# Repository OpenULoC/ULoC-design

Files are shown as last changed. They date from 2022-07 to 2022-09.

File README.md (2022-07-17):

# ULoC: design
Brainstorming and high-level [design](design.md) towards the ULoC.

## The ULoC
The **Universal Lab-on-a-Chip** (**ULoC**) is a hypotetical device capable of carrying out
a wide variety of laboratory tasks in an automatic, programmable manner.

In this regard, it seeks to provide the same advantages that a regular
[LoC](https://en.wikipedia.org/wiki/Lab-on-a-chip) offers, namely high throughput and low cost.
Additionally, the **OpenULoC** project is intended to create an Open Source incarnation
of this machine, opening up the doors to affordable research.

## Goals
Scientific research is neither cheap nor fast;
much of the funds are spent in expensive products and specialized equipment.
Cutting times or increasing quality is difficult,
as it often entails obtaining even less affordable equipment.

Same goes for medical practice.
There is an increasing market for biological and genetic therapies,
both of which are prohibitively expensive at the moment.
Reducing the barrier of entry to the manufacture of these products
could prove key to reducing health costs,
especially in developing countries.

## Scope
The ULoC will be initially limited to Molecular Biology experiments, tests and processes.
This is due to the fact that this field is effectively "low-hanging fruit" for
the goals exposed above, with many Cell Biology procedures depending on biomolecule products
and Organic Chemistry being very non-trivial to implement as solid-state circuitry.

This could include any of the following.

* Standard enzyme-catalyzed reactions.
* Nucleic acid amplification.
* Some antibody-mediated tests.
* Basic substance identification.
* _In vitro_ gene expression.
* _In vitro_ gene editing.
* Polynucleotide synthesis.

## Tools

> The trajectory of 3D printing will most certainly raise real grievances,
> from solid state meth labs, to ceramic knives.
> 
> - Cory Doctorow

This is a non-comprehensive list of tools that have been, or could be, helpful to this project.
They have been chosen over alternatives so as to avoid vendor lock or increasing costs.

* Standard FFF 3D printers
* [Cura by Ultimaker](https://github.com/Ultimaker/Cura)
* [OpenSCAD](https://github.com/openscad/openscad)
* [KiCAD](https://gitlab.com/kicad)
* [fluidics by aerkiaga](https://github.com/aerkiaga/fluidics)
* [OpenFOAM](https://github.com/OpenFOAM)
* [Rust](https://www.rust-lang.org/)

## Design
See [design.md](design.md).

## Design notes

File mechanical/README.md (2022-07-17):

# Mechanical design
The mechanical floor will output controlled rotary motion to the hydraulic floor above.
This motion will be carried via multiple transmission lines.

## Motors
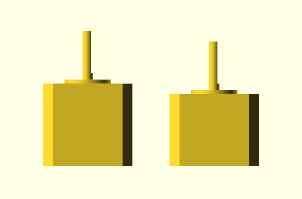
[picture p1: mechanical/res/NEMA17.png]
Two NEMA17 motors


Widely available **NEMA17** stepper motors will be used.
These are commonly used for consumer products such as
[3D printers](https://reprap.com/wiki/NEMA_Motor).

There's a table of widely available such motors
[here](https://reprap.org/wiki/NEMA_17_Stepper_motor#Common_Stepper_Motor_Models);
ideally, a wide variety of models from that table should be usable,
to allow scrap parts to be used (e.g. a typical 3D printer has exactly 4 steppers).

## Multiplexers
Due to the relatively high cost of stepper motors and the slow pace of typical experiments,
it only makes sense to use a small number of steppers and
couple them to many transmission lines by means of mechanical multiplexers.

A reasonable default would be two independent motors, each controlling a number of axes.
Since each multiplexer requires a further stepper to select the output axis,
that amounts to four motors in total, the exact number present in typical consumer 3D printers.

Ideally, the multiplexer itself should only consist of inexpensive, widely available
hardware store parts and 3D printed elements.

See [mux](mux.md) for designs.

## Transmission lines
There are many ways to transmit a rotating motion:

* Belts: low durability and accuracy; flexible but now always simple to implement.
* CV joints: good characteristics, but expensive.
* Bevel gears: complex but accurate, and cheap if 3D printed.

A nice solution is to use threaded rods and bevel gears at right angles.

See [elbow](elbow.md) for designs.

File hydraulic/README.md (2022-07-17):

# Hydraulic design
The hydraulic floor will receive mechanical input from the mechanical floor below.
It will contain syringe pumps and valves, and will connect via tubes to the floors above.
Any input and output containers will be situated outside the stack.

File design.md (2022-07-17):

# High-level design

## Design principles

* Open standards, open source
* Modularity and extensibility
* Low cost
* Reliability

## Block diagram

ULoC block diagram

The ULoC itself will consist of many layers or floors,
physically stacked over one another.
The first of these will contain an MCU and enough electronics to
control the machine and interface with a client machine.

The second floor will host [mechanical](mechanical/README.md) actuators and transmission mechanisms.
These should have a focus on affordability.

The third floor will contain syringe pumps, valves and other "clean"
[hydraulic](hydraulic/README.md) components.
These will receive input from all mechanical transmission lines arriving from below.
General inputs and outputs will be located outside the stack.

Finally, any subsequent floors will have room for the actual effectors and sensors,
including any fluidic channels and any electronics necessary for their operation.

All of this will be controlled by an Open Source firmware on the MCU and
a specialized software suite on the client machine (when connected).
This is quite a sweet spot for making sure the system is reliable.

Specialized laboratory protocols will be necessary,
those shall be encoded and provided for performing automated tasks and maintenance.

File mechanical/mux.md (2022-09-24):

# Mechanical multiplexer design

## Design 1
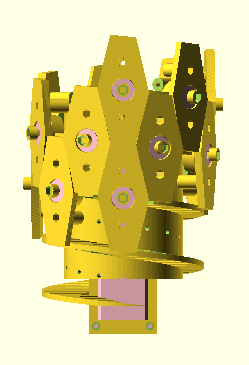
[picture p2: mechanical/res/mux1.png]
Design 1 in OpenSCAD


[Files](mux1)

A spiral staircase design.
Both motors are mounted inside the structure,
which rotates and moves to choose an axis.
It allows the number of axes to be easily and modularly increased.

Drawbacks:
* Only supports two specific motor models.
* The heavy motors are mounted inside the structure.
* Unnecessary friction between some moving parts.
* High vertical clearance needed.
* Complex design.

## Design 2
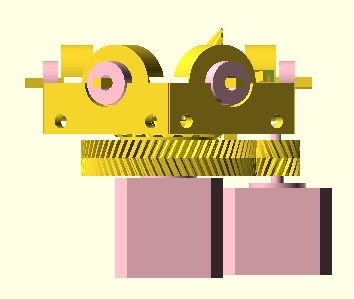
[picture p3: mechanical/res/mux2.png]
Design 2 in OpenSCAD


[Files](mux2)

A much simpler design.
Motors are fixed, and mounted underside the mechanism.
NEMA17 motors of any length can be used.
Makes use of adhesive to fix bearings in place.

Drawbacks:
* Structure may be unstable.
* Requires extra pieces for support, which depend on motor length.
* Fixed number of output axes: 6.
* To select a new axis, the input shaft must also be rotated in tandem.

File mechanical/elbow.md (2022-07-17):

# Geared elbow design

## Design 1
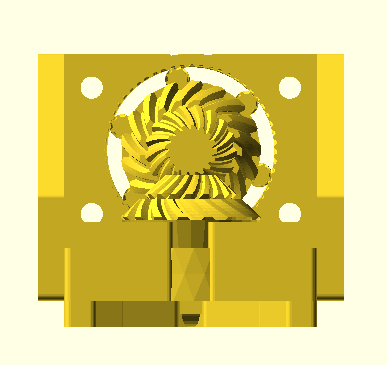
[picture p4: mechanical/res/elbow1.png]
Design 1 in OpenSCAD


[Files](elbow1)

A sturdy elbow with 3D printed gear bearings.
It's designed to connect two M5 threaded rods,
plus using a few M3 nuts and bolts in its build.
All remaining components can be 3D printed.

The design has been built, and unfortunately
the printed gear bearings quickly fail.

## Design 2
Work in progress, will use cheap ball bearings.

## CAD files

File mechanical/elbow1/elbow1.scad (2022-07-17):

use <../lib/octoid_gear_types.scad>
use <../lib/mesh_bevel_gear.scad>
use <../lib/gear_bearing.scad>

// 0 or undef for full assembly
// 1 - 5 for individual pieces
do_piece = undef;

// set true for final render
// set false for faster viewing
high_detail = true;


$fs = high_detail ? 0.3 : $fs;
$fn = high_detail ? 30 : $fn;

module half_elbow_mechanism(
    reverse = false, rotation = 0
) {
    angle = fn_bevel_angle_for_gear_ratio(1);
    height = sin(angle) * 15;
    radius = cos(angle) * 15;

    coef = 1.4;
    difference() {
        union() {
            intersection() {
                mirror([0, 0, 1]) cylinder(22, 20, 0);
                rotate(rotation, [0, 0, 1])
                octoid_helical_gear(
                    15, 0.7, false,
                    reverse ? -1 : 1,
                    angle, 17, addendum_coefficient = 0.6
                );
            }
            
            translate([0, 0, -9])
            rotate(rotation, [0, 0, 1])
            cylinder(2, 7, 6);
            
            intersection() {
                mirror([0, 0, 1]) cylinder(16, 12, 0);
                rotate(rotation, [0, 0, 1])
                octoid_helical_gear(
                    10.5, 0.5, false,
                    reverse ? 1 : -1,
                    angle, 17, addendum_coefficient = 0.6
                );
            }

            translate([0, 0, -coef*height])
                cylinder((coef-1)*height, 0.6*coef*radius, radius);
        
        
            translate([0, 0, -coef*height - 8])
                gear_bearing(
                    8, coef*radius, 0.6, false,
                    40, 6,
                    planet_tooth_count = 8,
                    rotation_angle = rotation,
                    tolerance = 0.2
                );
        }
        
        translate([0, 0, -coef*height - 8 - 0.1])
            cylinder(10 + 0.1, 2.75, 2.75); // M5 clearance hole, normal fit
                
        translate([0, 0, -coef*height + 2 - 0.1])
            cylinder(6, 2.75, 0);  
                
        translate([0, 0, -coef*height - 8 - 0.1])
        linear_extrude(4.7) // M5 hexagon nut height
        scale([4.4, 4.4]) // M5 hexagon nut radius
        polygon([
            for(phi = [0:60:360])
                [cos(phi), sin(phi)]
        ]);
                
        translate([0, 0, -coef*height - 3.3 - 0.1])
        linear_extrude(7, scale = 0)
        scale([4.4, 4.4])
        polygon([
            for(phi = [0:60:360])
                [cos(phi), sin(phi)]
        ]);
    }
}

module half_elbow_corners() {
    angle = fn_bevel_angle_for_gear_ratio(1);
    height = sin(angle) * 15;
    radius = cos(angle) * 15;
    
    coef = 1.4;
    inner_coord = 0.9*coef*radius/sqrt(2);
    
    translate([0, 0, -coef*height - 8])
    linear_extrude(8)
    for(phi = [0:90:360]) {
        rotate(2*phi, [0, 0, 1])
        scale([1, phi >= 180 ? -1 : 1, 1])
        difference() {
            offset(1)
            offset(-1)
            polygon([
                [coef*radius, 0],
                [coef*radius, 1.3*coef*radius],
                [-1, 1.3*coef*radius],
                [-1, 0.99*coef*radius],
                [1.11*inner_coord, 1.11*inner_coord],
                [0.9*coef*radius, 2]
            ]);
            translate([1.02*inner_coord, 1.6*inner_coord])
            circle(d=3.4); // M3 clearance hole, normal fit
        }
    }
}

module elbow_connector() {
    angle = fn_bevel_angle_for_gear_ratio(1);
    height = sin(angle) * 15;
    radius = cos(angle) * 15;
    
    coef = 1.4;
    inner_coord = 0.9*coef*radius/sqrt(2);
    clearance = 0.0;
    
    for(phi = [0:90:360]) {
        rotate(phi % 180 > 0 ? -90 : 0, [0, 1, 0])
        scale([phi % 180 > 0 ? -1 : 1, 1, 1])
        translate([0, 0, -coef*height - 12 - clearance])
        linear_extrude(4)
        scale([1, phi >= 180 ? -1 : 1, 1])
        difference() {
            offset(1)
            offset(-1)
            polygon([
                [1.5*coef*radius, 0],
                [1.5*coef*radius, 1.3*coef*radius],
                [-1, 1.3*coef*radius],
                [-1, 0.99*coef*radius],
                [1.11*inner_coord, 1.11*inner_coord],
                [0.9*coef*radius, 2]
            ]);
            translate([1.02*inner_coord, 1.6*inner_coord])
            circle(d=3.4); // M3 clearance hole, normal fit
        }
    }
    
    translate([
        coef*height + clearance,
        1.3*coef*radius,
        -coef*height - clearance
    ])
    mirror([0, 0, 1])
    rotate(90, [1, 0, 0])
    linear_extrude(2.6*coef*radius)
    {
        square(10);
        
        offset(5)
        offset(-5)
        square(12);
    }
}

module elbow_support() {
    angle = fn_bevel_angle_for_gear_ratio(1);
    height = sin(angle) * 15;
    radius = cos(angle) * 15;
    
    coef = 1.4;
    inner_coord = 0.9*coef*radius/sqrt(2);
    clearance = 0.0;
    
    for(phi = [0:90:180]) {
        rotate(phi % 180 > 0 ? -90 : 0, [0, 1, 0])
        scale([phi % 180 > 0 ? -1 : 1, 1, 1])
        translate([0, 0, -coef*height + clearance])
        linear_extrude(4)
        scale([-1, 1, 1])
        difference() {
            offset(1)
            offset(-1)
            polygon([
                [coef*radius, 0],
                [coef*radius, 1.5*coef*radius],
                [-1, 1.5*coef*radius],
                [-1, 0.99*coef*radius],
                [1.11*inner_coord, 1.11*inner_coord],
                [0.9*coef*radius, 2]
            ]);
            translate([1.02*inner_coord, 1.6*inner_coord])
            circle(d=3.4); // M3 clearance hole, normal fit
        }
    }
    
    translate([
        coef*radius - clearance,
        1.3*coef*radius + clearance,
        -coef*radius + clearance
    ])
    rotate(-90, [1, 0, 0])
    rotate(180, [0, 0, 1])
    linear_extrude(4 - clearance)
    offset(1)
    offset(-1)
    polygon([
        [-8, -8],
        [2*coef*radius - clearance, -8],
        [2*coef*radius - clearance, 8 - clearance],
        [8 - clearance, 2*coef*radius - clearance],
        [-8, 2*coef*radius - clearance]
    ]);
}

/// FULL ANIMATED ASSEMBLY ///
rotate(360 * $t, [0, 0, 1])
if(!do_piece) {
    half_elbow_mechanism(false, 360 * $t);
    half_elbow_corners();
    mesh_bevel_gear(0, 1, 17)
        half_elbow_mechanism(true, -360 * $t);
    rotate(90, [0, -1, 0])
        half_elbow_corners();
    elbow_connector();
    elbow_support();
    mirror([0, 1, 0])
        elbow_support();
}

/// PIECE 1 ///
if(do_piece == 1) {
    half_elbow_mechanism(false);
    half_elbow_corners();
}

/// PIECE 2 ///
if(do_piece == 2) {
    half_elbow_mechanism(true);
    half_elbow_corners();
}

/// PIECE 3 ///
if(do_piece == 3) {
    elbow_connector();
}

/// PIECE 4 ///
if(do_piece == 4) {
    rotate(-90, [1, 0, 0])
        elbow_support();
}

/// PIECE 5 ///
if(do_piece == 5) {
    rotate(90, [1, 0, 0])
    mirror([0, 1, 0])
        elbow_support();
}

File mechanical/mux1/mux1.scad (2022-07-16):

use <../lib/cycloid_gear_types.scad>
use <../lib/mesh_parallel_gear.scad>

// 0 or undef for full assembly
// 1 - 12 for individual pieces
do_piece = undef;

/*
Piece   Count   Description
1       1       Motor housing half 1
2       1       Motor housing half 2
3       1       Output segment
4       1       Sun gear
5       2       Planet gear
6       1       Helix, bottom
7       1       Helix, top
8       1       Fixed gear
9       15      Output shaft
10      15      Output adapter
11      15      Output housing
12      1       Base
*/

// set true for final render
// set false for faster viewing
high_detail = true;


$fs = high_detail ? 0.1 : $fs;
$fn = high_detail ? 100 : $fn;

module NEMA17_motor(length) {
    linear_extrude(length)
    polygon([
        /*[21.15, 15.5],
        [15.5, 21.15],
        [-15.5, 21.15],
        [-21.15, 15.5],
        [-21.15, -15.5],
        [-15.5, -21.15],
        [15.5, -21.15],
        [21.15, -15.5],*/
        [21.15, 16.5],
        [16.5, 21.15],
        [-16.5, 21.15],
        [-21.15, 16.5],
        [-21.15, -16.5],
        [-16.5, -21.15],
        [16.5, -21.15],
        [21.15, -16.5],
    ]);
    translate([0, 0, length])
    cylinder(2, d=22, false);
    translate([0, 0, length])
    difference() {
        cylinder(25, d=5, false);
        translate([4, 0, 15])
        cube([5, 5, 20], true);
    }
}

module bearing_606_2RS() {
    difference() {
        cylinder(6, d=17, false);
        translate([0, 0, -0.5])
        cylinder(7, d=6, false);
    }
}

module M3_bolt() {
    cylinder(20, d=3.4);
    mirror([0, 0, 1])
    cylinder(2, d=6);
}

module M3_hexagon_profile() {
    //radius = 3.2;
    radius = 3.5;
    polygon([ for(phi = [0:60:360]) [
        radius * cos(phi), radius * sin(phi)
    ]]);
}

module stacked_motors() {
    //small motor
    translate([-17, 0, 0])
    rotate(90, [0, 1, 0])
    NEMA17_motor(34);
    //large motor
    rotate(180, [0, 0, 1])
    translate([0, 0, -25 - 39 - 21.3 - 5])
    NEMA17_motor(39);
}

module m3_hole(y, z) {
    translate([0, y, z])
    rotate(90, [0, 1, 0]) {
        translate([0, 0, -20])
            cylinder(50, d=3.4, false);
        translate([0, 0, -20])
            cylinder(12, d=6, false);
        translate([0, 0, 20])
        mirror([0, 0, 1])
        linear_extrude(13)
            M3_hexagon_profile();
    }
}

module motor_housing() {
    difference() {
        translate([0, 0, -35.5])
            cube([38, 50, 130], true);
        stacked_motors();
        translate([-10, 0, 25])
            cube([20, 20, 12], true);
        translate([0, 0, -35])
            cube([30, 60, 24], true);
        m3_hole(20, 22);
        m3_hole(-20, 22);
        m3_hole(20, -95);
        m3_hole(-20, -95);
    }
}

module helix(
    turns = 4,
    inner_radius = 27,
    outer_radius = 60,
    turn_height = 40,
    height_proportion = 0.1
) {
    height = turn_height * turns;
    twist = 360 * turns;
    angle = height_proportion * 180;
    
    intersection() {
        linear_extrude(height, twist = twist, slices = turns * 3 * $fn, convexity = turns + 1)
        rotate(-angle, [0, 0, 1])
        projection()
        rotate_extrude(angle = 2 * angle, convexity = 1)
        polygon([
            [1.2*outer_radius, 1],
            [1.2*outer_radius, -1],
            [inner_radius, -1],
            [inner_radius, 1]
        ]);
        cylinder(height, r=outer_radius);
    }
}

module output_sector() {
    difference() {
        rotate(180, [1, 0, 0])
        intersection() {
            union() {
                translate([0, 0, -40])
                    helix(4, 45);
                rotate(90, [0, 1, 0])
                    cylinder(49, 3.5, 3.5);
            }
            rotate(90, [0, 1, 0])
                cylinder(60, 0, 20);
        }
        translate([0, 0, -10])
            cylinder(20, r=25, true);
        stacked_motors();
    }
}

sun_teeth = 16;
sun_radius = 5;
fixed_radius = 35;

fixed_teeth = sun_teeth * fixed_radius / sun_radius;
planet_radius = (fixed_radius - sun_radius) / 2;
planet_teeth = sun_teeth * planet_radius / sun_radius;

module fixed_helix() {
    difference() {
        translate([0, 0, -80])
            helix(4, 0);
        rotate(90, [0, 1, 0])
            cylinder(110, 0, 45);
        translate([0, 0, -32.5])
            cube([38, 50, 127], true);
        stacked_motors();
        translate([0, -sun_radius - planet_radius, -40])
            cylinder(20, 1.1*planet_radius, 1.1*    planet_radius);
        translate([0, sun_radius + planet_radius, -60])
            cylinder(20, 1.1*planet_radius, 1.1*    planet_radius);
    }
}

module fixed_gear() {
    difference() {
        translate([0, 0, -60])
        cycloid_spur_gear(130, fixed_radius, false,
            fixed_teeth, true, 44);
        translate([0, 0, -80])
        helix(4, 0, 60, 40, 0.2);
        for(phi = [-360:360/15:864]) {
            translate([0, 0, 40 * phi / 360])
            rotate(-phi, [0, 0, 1]) {
                translate([fixed_radius + 3, 0, 0])
                rotate(90, [0, 1, 0])
                translate([20, 0, 0]) {
                    M3_bolt();
                    translate([0, 0, -10])
                    cylinder(10, d=6);
                }
            }
        }
    }
}

module sun_gear() {
    difference() {
        translate([0, 0, -45])
        cycloid_spur_gear(20, sun_radius, false, sun_teeth);
        stacked_motors();
    }
}

module planet_gear(angle = 90) {
    translate([0, 0, -45])
    mesh_parallel_gear(sun_radius + planet_radius, angle,
        planet_teeth / fixed_teeth, true, planet_teeth)
    difference() {
        cycloid_spur_gear(20, planet_radius, false, planet_teeth);
        cylinder(4, d=17.1);
    }
}

module output_shaft() {
    difference() {
        rotate(90, [0, 1, 0])
        union() {
            difference() {
                cylinder(60, 0, 15);
                cylinder(50, 0, 15);
            }
            translate([0, 0, 60 + 3])
            cube([6/sqrt(2), 6/sqrt(2), 3], true);
        }
        translate([0, 0, -40])
        helix();
    }
}

module planet_bearing(angle = 90) {
    translate([0, 0, -47])
    mesh_parallel_gear(sun_radius + planet_radius, angle, 1, true, 1)
    color("pink")
        bearing_606_2RS();
}

module output_adapter() {
    rotate(90, [0, 1, 0])
    translate([0, 0, 60 + 7])
    union() {
        translate([0, 0, 1])
        difference() {
            cylinder(6, d=10, false);
            translate([0, 0, 6 - 4.7])
            linear_extrude(4.7 + 0.1)
            // M5 nut
            polygon([ for(phi = [0:60:360]) [
                4.12 * cos(phi), 4.12 * sin(phi)
            ]]);
        }
        cube([6/sqrt(2), 6/sqrt(2), 5], true);
    }
}

module output_housing() {
    angle = 720/15;
    inner_apotheme = 61;
    outer_apotheme = 67;
    outer_side = outer_apotheme * tan(angle/2) * 2;
    third_side = outer_apotheme * tan(angle/3);
    step = 40 * angle / 360;
    
    difference() {
        translate([outer_apotheme, 0, 0])
        rotate(-90, [0, 1, 0]) {
            linear_extrude(outer_apotheme - inner_apotheme,
                scale = [1, inner_apotheme / outer_apotheme],
                convexity = 4
            )
            difference() {
                polygon([
                    [40 - step/6, third_side/2],
                    [40 + step/6, -third_side/2],
                    [0 + step/3, -third_side],
                    [-40 + step/6, -third_side/2],
                    [-40 - step/6, third_side/2],
                    [0 - step/3, third_side]
                ]);
                circle(d=18);
                translate([20, 0, 0])
                M3_hexagon_profile();
                translate([-20, 0, 0])
                M3_hexagon_profile();
            }
            
            translate([0, 0, outer_apotheme - inner_apotheme])
            linear_extrude(10, convexity=4)
            difference() {
                union() {
                    translate([20, 0, 0])
                        circle(d=10);
                    translate([-20, 0, 0])
                        circle(d=10);
                }
                translate([20, 0, 0])
                M3_hexagon_profile();
                translate([-20, 0, 0])
                M3_hexagon_profile();
            }
            
            translate([0, 0, outer_apotheme - inner_apotheme + 10])
            linear_extrude(20, convexity=4)
            difference() {
                union() {
                    translate([20, 0, 0])
                        circle(d=10);
                    translate([-20, 0, 0])
                        circle(d=10);
                }
                translate([20, 0, 0])
                    circle(d=3.4);
                translate([-20, 0, 0])
                    circle(d=3.4);
            }
        }
        translate([0, 0, -50])
        cylinder(100, r=44);
    }
}

module structure_base() {
    // TODO
}
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

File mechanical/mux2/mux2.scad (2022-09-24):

use <../lib/octoid_gear_types.scad>
use <../lib/mesh_bevel_gear.scad>
use <../lib/involute_gear_types.scad>
use <../lib/mesh_parallel_gear.scad>

// 0 or undef for full assembly
// 1 - 7 for individual pieces
do_piece = undef;

/*
Piece   Count   Description
1       1       Bottom gear
2       1       Side gear
3       1       Side axis
4       1       Outer gear
5       1       Small gear
6       6       Output gear
7       1       Crown
*/

// set true for final render
// set false for faster viewing
high_detail = true;


$fs = high_detail ? 0.1 : $fs;
$fn = high_detail ? 100 : $fn;

module NEMA17_motor(length) {
    linear_extrude(length)
    polygon([
        /*[21.15, 15.5],
        [15.5, 21.15],
        [-15.5, 21.15],
        [-21.15, 15.5],
        [-21.15, -15.5],
        [-15.5, -21.15],
        [15.5, -21.15],
        [21.15, -15.5],*/
        [21.15, 16.5],
        [16.5, 21.15],
        [-16.5, 21.15],
        [-21.15, 16.5],
        [-21.15, -16.5],
        [-16.5, -21.15],
        [16.5, -21.15],
        [21.15, -16.5],
    ]);
    translate([0, 0, length])
    cylinder(2, d=22, false);
    translate([0, 0, length])
    difference() {
        cylinder(25, d=5, false);
        translate([4, 0, 15])
        cube([5, 5, 20], true);
    }
}

module bearing_606_2RS() {
    difference() {
        cylinder(6, d=17, false);
        translate([0, 0, -0.5])
        cylinder(7, d=6, false);
    }
}

angle = fn_bevel_angle_for_gear_ratio(1);
height = sin(angle) * 30;
radius = cos(angle) * 30;

coef = 1.4;

module double_gear(rotation = 0, reverse = false) {
    intersection() {
        mirror([0, 0, 1]) cylinder(44, 40, 0);
        rotate(rotation, [0, 0, 1])
        octoid_helical_gear(
            30, 0.7, false,
            reverse ? -1 : 1,
            angle, 17, addendum_coefficient = 0.6
        );
    }
    
    intersection() {
        mirror([0, 0, 1]) cylinder(32, 24, 0);
        rotate(rotation, [0, 0, 1])
        octoid_helical_gear(
            21, 0.5, false,
            reverse ? 1 : -1,
            angle, 17, addendum_coefficient = 0.6
        );
    }
}

module bottom_gear(rotation = 0) {
    difference() {
        union() {
            double_gear(rotation);
            
            translate([0, 0, -coef*height - 5])
            cylinder((coef-1)*height + 5, 0.9 * radius, 0.9 * radius);
        }
        
        translate([0, 0, -coef*height - 5 - 0.1])
            cylinder(25 + 0.1, 6/2, 6/2); // NEMA17 clearance hole
    }
}

gear_height = 20;

module side_gear(rotation = 0) {
    difference() {
        double_gear(rotation);
        
        translate([0, 0, -coef*height - 0.1])
        linear_extrude(gear_height + 0.1)
            square(4.5, center = true);
    }
}

contact_radius = 40;
segment_angle = 60;
segment_coeff = 0.7;
strip_width = contact_radius - coef*height;
strip_thickness = 4;

module side_axis(rotation = 0) {
    rotate(rotation, [0, 0, 1]) {
        translate([0, 0, -coef*height]) {
            linear_extrude(15 + 0.1)
                square(4, center = true);
        }
        rotate(90, [0, 1, 0])
        rotate(-segment_coeff * segment_angle / 2, [0, 0, 1])
        rotate_extrude(angle = segment_coeff * segment_angle)
        translate([coef*height, -2])
            square([strip_width - 0.5, strip_thickness]);
    }
}

fixator_height = 30;
outer_gear_height = 0.7 * gear_height;
outer_coef = 1.6;

module outer_gear() {
    difference() {
        translate([height + 3, 0, -fixator_height/2])
            cube([5, 20, fixator_height], center = true);
        rotate(90, [0, 1, 0])
        translate([0, 0, height + 0.1])
            cylinder(6, d=18, false);
    }
    translate([0, 0, -height - outer_gear_height - 1])
    difference() {
        involute_herringbone_gear(outer_gear_height, outer_coef*radius, false, 1, 4*17);
        cylinder(2*outer_gear_height + 0.1, 0.92*radius, 0.92*radius, center = true);
    }
}

module small_gear() {
    translate([0, 0, -height - outer_gear_height - 1])
    difference() {
        involute_herringbone_gear(outer_gear_height, (outer_coef/4)*radius, false, 1, 17);
        cylinder(outer_gear_height + 0.1, 6/2, 6/2); // NEMA17 clearance hole
    }
}

output_radius = 15;

module output_wheel(rotation = 0) {
    translate([0, 0, contact_radius - strip_width])
    rotate(rotation, [0, 0, 1])
    difference() {
        cylinder(strip_width + 2, output_radius, output_radius);
        translate([0, 0, strip_width/2])
            cube([5, 30 + 0.1, strip_width + 2], center = true);
    }
    translate([0, 0, contact_radius + 1])
    linear_extrude(15 + 0.1)
        square(4, center = true);
}

crown_apotheme = contact_radius + strip_width/2 - 1;
crown_height = 20;

module crown() {
    mirror([0, 0, 1])
    for(phi = [0:360/6:5*360/6]) {
        rotate(phi, [0, 0, 1])
        rotate(90, [0, 1, 0])
        translate([0, 0, crown_apotheme])
        linear_extrude(5)
        difference() {
            translate([-crown_height/2, 0, 0])
                square([crown_height, crown_apotheme / cos(30) + 5], center = true);
            circle(17/2 + 1);
            translate([-15, 0.8 * crown_apotheme / cos(30) / 2, 0])
                circle(2.75); // M5 clearance hole, normal fit
            translate([-15, -0.8 * crown_apotheme / cos(30) / 2, 0])
                circle(2.75); // M5 clearance hole, normal fit
        }
    }
}

/// FULL ANIMATED ASSEMBLY ///
if(!do_piece) {
    bottom_gear(360 * $t);
    mesh_bevel_gear(0, 1, 17) {
        side_gear(-360 * $t);
        side_axis(-360 * $t);
        color("pink")
        mirror([0, 0, 1])
        translate([0, 0, height + 0.1])
            bearing_606_2RS();
        mirror([0, 0, 1]) {
            output_wheel(-360 * $t);
            color("pink")
            translate([0, 0, contact_radius + strip_width/2 - 2])
                bearing_606_2RS();
        }
    }
    outer_gear();
    mesh_parallel_gear((outer_coef + outer_coef/4)*radius, 0, 4, false, 17)
        small_gear();
    for(phi = [360/6:360/6:5*360/6]) {
        rotate(phi, [0, 0, 1])
        rotate(90, [0, 1, 0]) {
            output_wheel(-360 * $t);
            color("pink")
            translate([0, 0, contact_radius + strip_width/2 - 2])
                bearing_606_2RS();
        }
    }
    color("pink")
    translate([0, 0, -39 - height - gear_height + 4])
        NEMA17_motor(39);
    color("pink")
    translate([outer_coef*1.25*radius, 0, -34 - height - gear_height])
        NEMA17_motor(34);
    crown();
}

/// PIECE 1 ///
if(do_piece == 1) {
    bottom_gear();
}

/// PIECE 2 ///
if(do_piece == 2) {
    side_gear();
}

/// PIECE 3 ///
if(do_piece == 3) {
    rotate(90, [0, -1, 0])
        side_axis();
}

/// PIECE 4 ///
if(do_piece == 4) {
    outer_gear();
}

// PIECE 5
if(do_piece == 5) {
    small_gear();
}

// PIECE 6
if(do_piece == 6) {
    output_wheel();
}

// PIECE 7
if(do_piece == 7) {
    crown();
}

//mirror([0, 0, 1]) cube(100);

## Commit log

2022-07-16 Add mux1 design
    [mux1.scad]
2022-07-17 Add elbow design
    [elbow.scad]
2022-09-24 Added mux2 design
    [elbow1.scad, mux2.scad]
